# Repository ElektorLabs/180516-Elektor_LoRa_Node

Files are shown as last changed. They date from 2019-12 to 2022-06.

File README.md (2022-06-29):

# Elektor LoRa Node

## This is a Elektor LoRa Node based on a STM32F072

This is the hardware and software repository for the Elektor LoRa node.
This is open hardware under the CERN OHL v1.2, so feel free to grab your copy and have fun. 
Also this project is done with KiCad, so you can have a look at the files without software that costs a fortune.

Under the Hardware folder you will find (besides the project files) the PDF files for the board schematics.  

For more information and the motivation also to share the KiCad files with you have a look at https://www.elektormagazine.com/labs/lorawan-node-experimental-platform
If you are new to KiCad and would like to modify the PCB on your own, feel free, and if you need a good book to start with KiCad have a look at: https://www.elektor.com/kicad-like-a-pro

## Getting Started

Grab a copy of KiCad and download the repository, or just grab the schematics to get an idea of the board.

For the software grab a copy of the Arduino IDE and install the STM32 core support for Arduino ( https://github.com/stm32duino/Arduino_Core_STM32 )
You can use the excellent guide provided here : https://github.com/stm32duino/Arduino_Core_STM32#getting-started

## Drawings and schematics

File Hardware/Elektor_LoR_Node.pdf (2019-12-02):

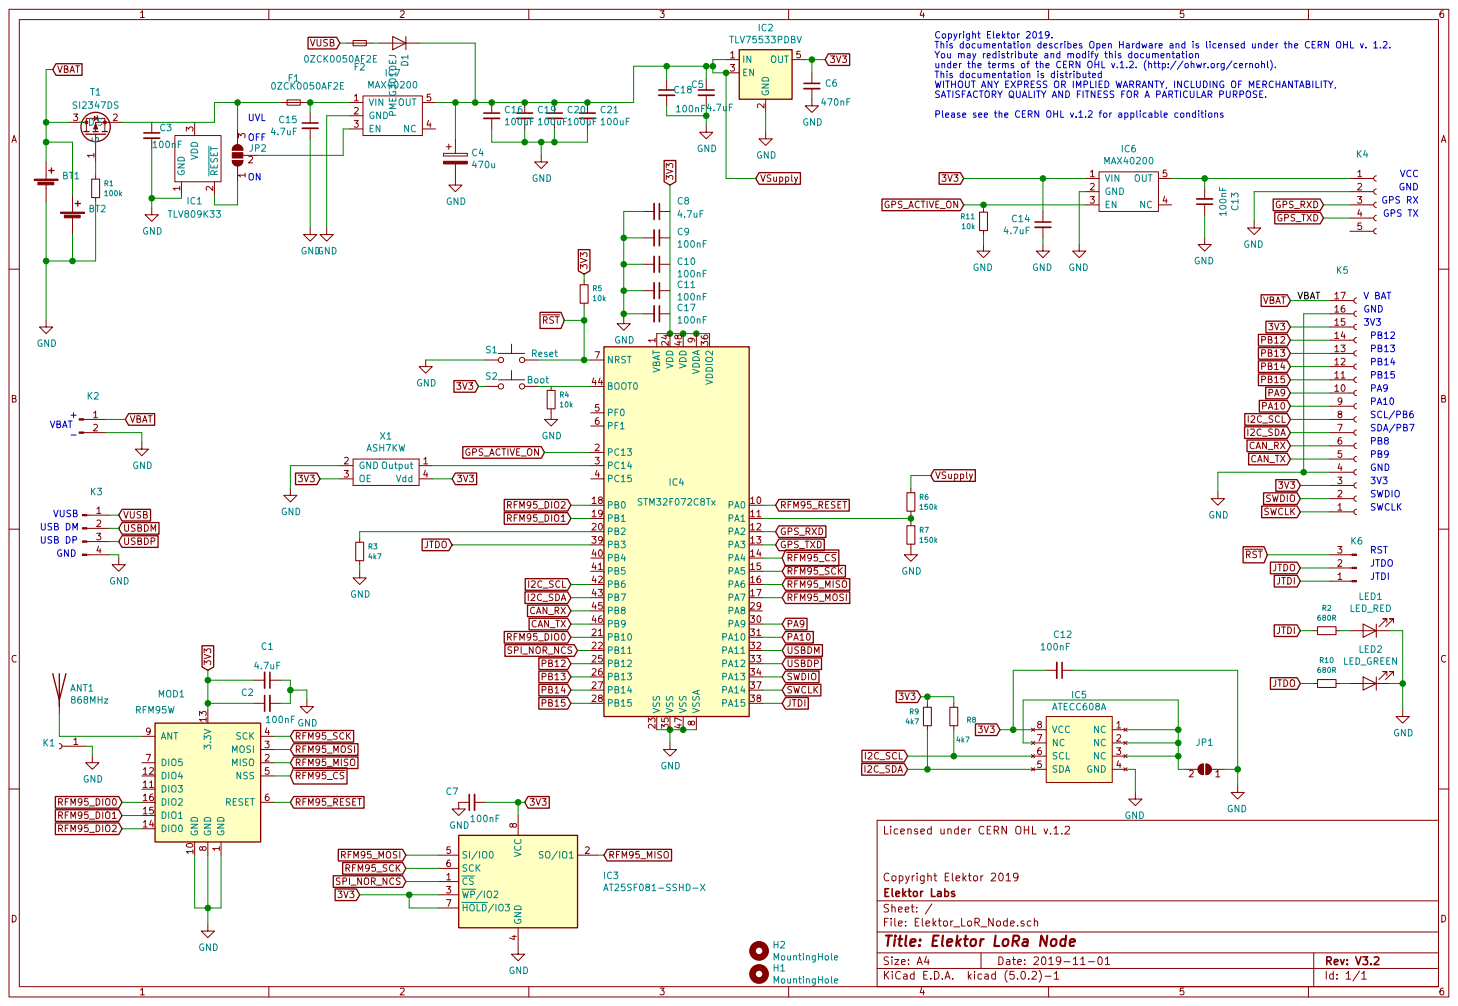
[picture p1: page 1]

Copyright Elektor 2019.
This documentation describes Open Hardware and is licensed under the CERN OHL v. 1.2.
You may redistribute and modify this documentation
under the terms of the CERN OHL v.1.2. (http://ohwr.org/cernohl). This documentation is distributed WITHOUT ANY EXPRESS OR IMPLIED WARRANTY, INCLUDING OF MERCHANTABILITY, SATISFACTORY QUALITY AND FITNESS FOR A PARTICULAR PURPOSE. Please see the CERN OHL v.1.2 for applicable conditions

- GPS TX GPS RX GND

9 VDDIO2 36 VSS 23 VSS 35 VSS 47 VSSA

SWCLK VUSB USB DM

1 GND 10 DIO3 11 DIO4 12 3.3V 13 DIO0 14 DIO1 15 DIO2 16 MISO 2 MOSI 3 SCK 4 NSS 5 RESET 6 DIO5 7 GND

4 SI/IO0 5 SCK 6 HOLD/IO3 7 VCC

Id: 1/1 Title: Elektor LoRa Node

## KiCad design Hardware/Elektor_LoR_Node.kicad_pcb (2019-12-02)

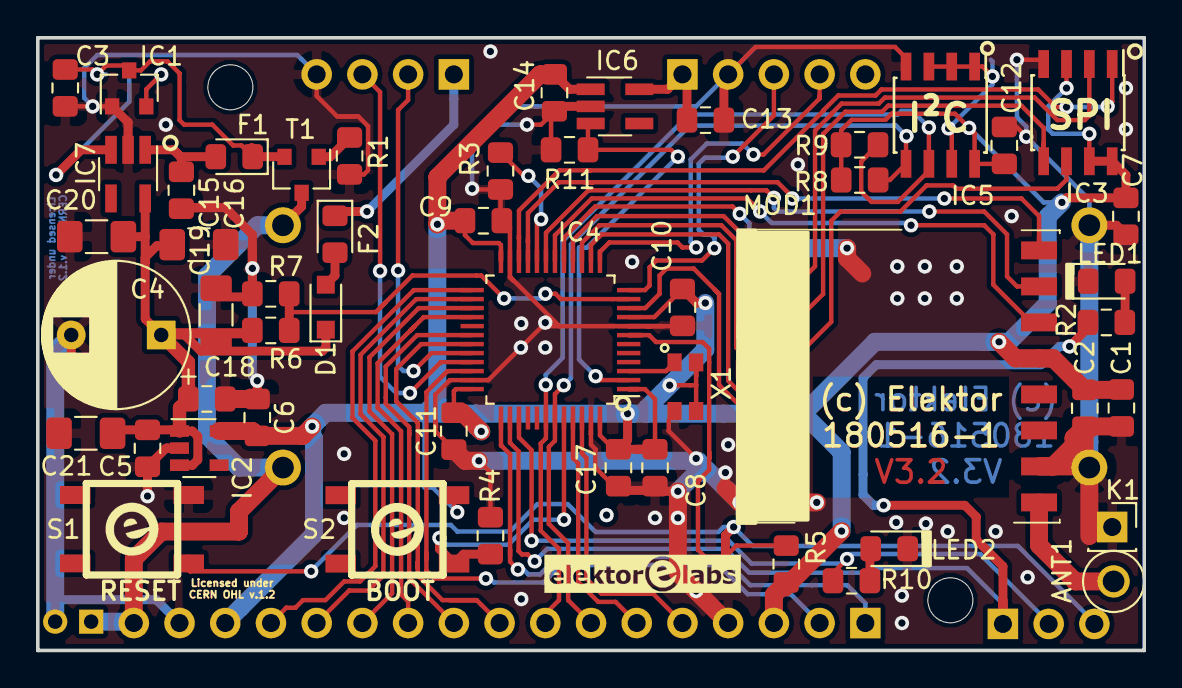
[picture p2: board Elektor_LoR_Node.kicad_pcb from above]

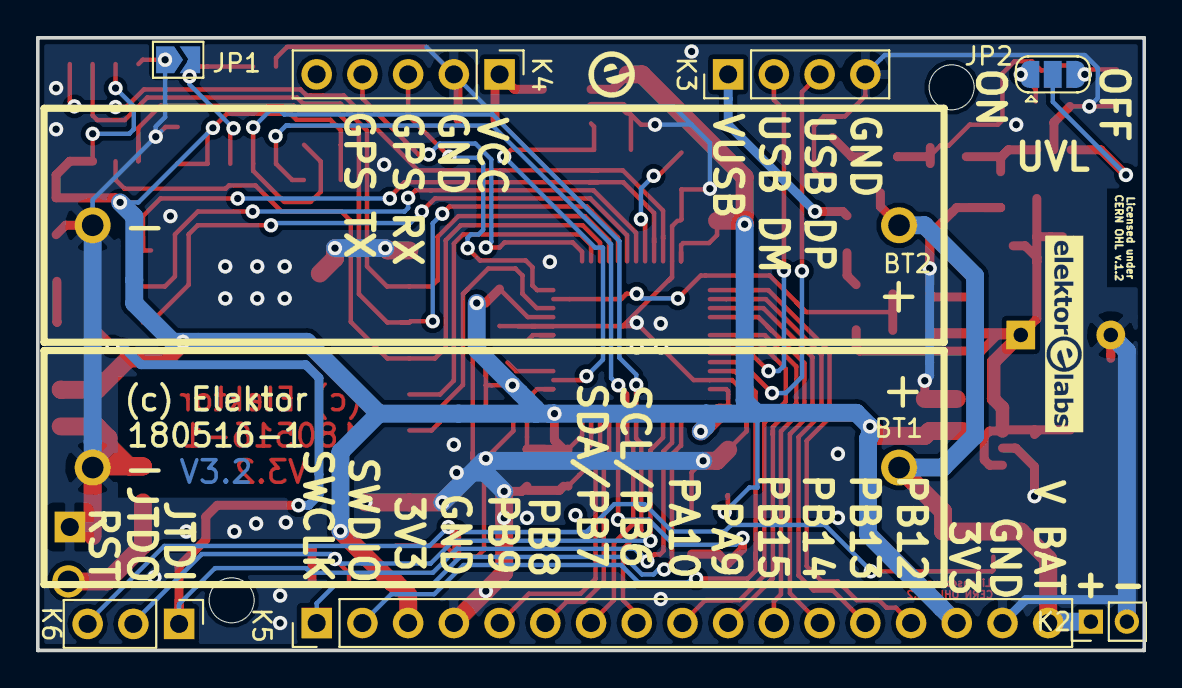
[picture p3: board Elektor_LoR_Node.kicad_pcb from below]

Board: 2 copper layers, 61.5 x 34.0 mm, 62 parts (9 on the bottom side), 49 nets.

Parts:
ANT1: Antenna; TestPoint_Plated_Hole_D2.0mm
BT1, BT2: multicomp pro AAA Battery Holder with PCB Pins; AAA_holder
C1, C5, C8, C14, C15: 4.7uF; C_0805_2012Metric_Pad1.15x1.40mm_HandSolder
C2, C3, C6, C7, C9, C10, C11, C12, C13, C17, C18: 100nF; C_0805_2012Metric_Pad1.15x1.40mm_HandSolder
C4: 470u; CP_Radial_D8.0mm_P5.00mm
C16, C19, C20, C21: 100uF; C_1206_3216Metric_Pad1.42x1.75mm_HandSolder
D1: PMEG3010EJ; D_SOD-323_HandSoldering
F1, F2: 0ZCK0050AF2E; D_0805_2012Metric_Pad1.15x1.40mm_HandSolder
H1, H2: MountingHole; MountingHole_2.5mm
IC1: TLV809K33; SOT-23
IC2: TLV75533PDBV; SOT-23-5
IC3: AT25SF081-SSHD-X; SOIC-8_3.9x4.9mm_P1.27mm
IC4: STM32F072C8Tx; LQFP-48_7x7mm_P0.5mm
IC5: ATECC608A; SOIC-8_3.9x4.9mm_P1.27mm
IC6, IC7: MAX40200; SOT-23-5_HandSoldering
JP1: SolderJumper_2_Open; SolderJumper-2_P1.3mm_Open_TrianglePad1.0x1.5mm
JP2: SolderJumper_3_Open; SolderJumper-3_P1.3mm_Open_RoundedPad1.0x1.5mm
K1: Conn_01x01_Female; PinSocket_1x01_P2.54mm_Vertical
K2: Conn_01x02_Male; PinHeader_1x02_P2.00mm_Vertical
K3: Conn_01x04_Male; PinHeader_1x04_P2.54mm_Vertical
K4: Conn_01x05_Female; PinHeader_1x05_P2.54mm_Vertical
K5: Conn_01x17_Female; PinHeader_1x17_P2.54mm_Vertical
K6: Conn_01x03_Male; PinHeader_1x03_P2.54mm_Vertical
LED1: LED_RED; LED_0805_2012Metric_Pad1.15x1.40mm_HandSolder
LED2: LED_GREEN; LED_0805_2012Metric_Pad1.15x1.40mm_HandSolder
MOD1: RFM95W-868S2; RFM9xW-Compact
R1: 100k; R_0805_2012Metric_Pad1.15x1.40mm_HandSolder
R2, R10: 680R; R_0805_2012Metric_Pad1.15x1.40mm_HandSolder
R3, R8, R9: 4k7; R_0805_2012Metric_Pad1.15x1.40mm_HandSolder
R4, R5, R11: 10k; R_0805_2012Metric_Pad1.15x1.40mm_HandSolder
R6, R7: 150k; R_0805_2012Metric_Pad1.15x1.40mm_HandSolder
S1: Reset; SMT switch TL3342
S2: Boot; SMT switch TL3342
T1: SI2347DS; SOT-23
X1: ASH7KW; ABRACON-ASH7KW

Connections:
3V3: C1.2, C2.1, C6.1, C7.2, C8.1, C9.1, C10.1, C11.1, C12.2, C14.1, C17.1, IC2.5, IC3.3, IC3.7, IC3.8, IC4.1, IC4.9, IC4.24, IC4.36, IC4.48, IC5.8, IC6.1, K5.3, K5.15, MOD1.13, R5.2, R8.1, R9.1, S2.1, X1.3, X1.4
CAN_RX: IC4.45, K5.6
CAN_TX: IC4.46, K5.5
GND: BT1.2, BT2.2, C1.1, C2.2, C3.2, C4.2, C5.2, C6.2, C7.1, C8.2, C9.2, C10.2, C11.2, C12.1, C13.1, C14.2, C15.2, C16.2, C17.2, C18.2, C19.2, C20.2, C21.2, IC1.1, IC2.2, IC3.4, IC4.8, IC4.23, IC4.35, IC4.47, IC5.4, IC6.2, IC7.2, JP1.1, K1.1, K2.2, K3.4, K4.2, K5.4, K5.16, LED1.1, LED2.1, MOD1.1, MOD1.8, MOD1.10, R1.2, R3.2, R4.2, R7.2, R11.2, S1.1, X1.2
GPS_ACTIVE_ON: IC4.2, IC6.3, R11.1
GPS_RXD: IC4.12, K4.3
GPS_TXD: IC4.13, K4.4
I2C_SCL: IC4.42, IC5.6, K5.8, R8.2
I2C_SDA: IC4.43, IC5.5, K5.7, R9.2
JTDI: IC4.38, K6.1, R2.2
JTDO: IC4.39, K6.2, R10.1
unnamed: ANT1.1, MOD1.9
unnamed: C3.1, F1.1, IC1.3, JP2.3, T1.2
unnamed: C13.2, IC6.5, K4.1
unnamed: C15.1, F1.2, IC7.1
unnamed: D1.2, F2.2
unnamed: IC1.2, JP2.1
unnamed: IC4.3, X1.1
unnamed: IC4.11, R6.2, R7.1
unnamed: IC4.20, R3.1
unnamed: IC4.44, R4.1, S2.2
unnamed: IC5.1, IC5.2, IC5.3, IC5.7, JP1.2
unnamed: IC7.3, JP2.2
unnamed: LED1.2, R2.1
unnamed: LED2.2, R10.2
unnamed: R1.1, T1.1
RFM95_DIO0: IC4.21, MOD1.16
RFM95_DIO1: IC4.19, MOD1.15
RFM95_DIO2: IC4.18, MOD1.14
RFM95_MISO: IC3.2, IC4.16, MOD1.2
RFM95_MOSI: IC3.5, IC4.17, MOD1.3
RFM95_RESET: IC4.10, MOD1.6
RFM95_SCK: IC3.6, IC4.15, MOD1.4
SPI_NOR_NCS: IC3.1, IC4.22
SWCLK: IC4.37, K5.1
SWDIO: IC4.34, K5.2
UNUSED_00: IC4.25, K5.14
UNUSED_01: IC4.26, K5.13
UNUSED_02: IC4.27, K5.12
UNUSED_03: IC4.28, K5.11
UNUSED_04: IC4.30, K5.10
UNUSED_05: IC4.31, K5.9
USBDM: IC4.32, K3.2
USBDP: IC4.33, K3.3
VBAT: BT1.1, BT2.1, K2.1, K5.17, T1.3
VSupply: C4.1, C5.1, C16.1, C18.1, C19.1, C20.1, C21.1, D1.1, IC2.1, IC2.3, IC7.5, R6.1
VUSB: F2.1, K3.1
~RFM95_CS: IC4.14, MOD1.5
~RST: IC4.7, K6.3, R5.1, S1.2

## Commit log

2019-11-08 Version 3.1
    Small changes towards V3.2 already done for cleanup and bugfixing
    [LoRa_Tracker.sch]
2019-12-02 Files for Version 3.2
    Fixed library problems within the project
    [Elektor_LoR_Node.kicad_pcb, Elektor_LoR_Node.sch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]

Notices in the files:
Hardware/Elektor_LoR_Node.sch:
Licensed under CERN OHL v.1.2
